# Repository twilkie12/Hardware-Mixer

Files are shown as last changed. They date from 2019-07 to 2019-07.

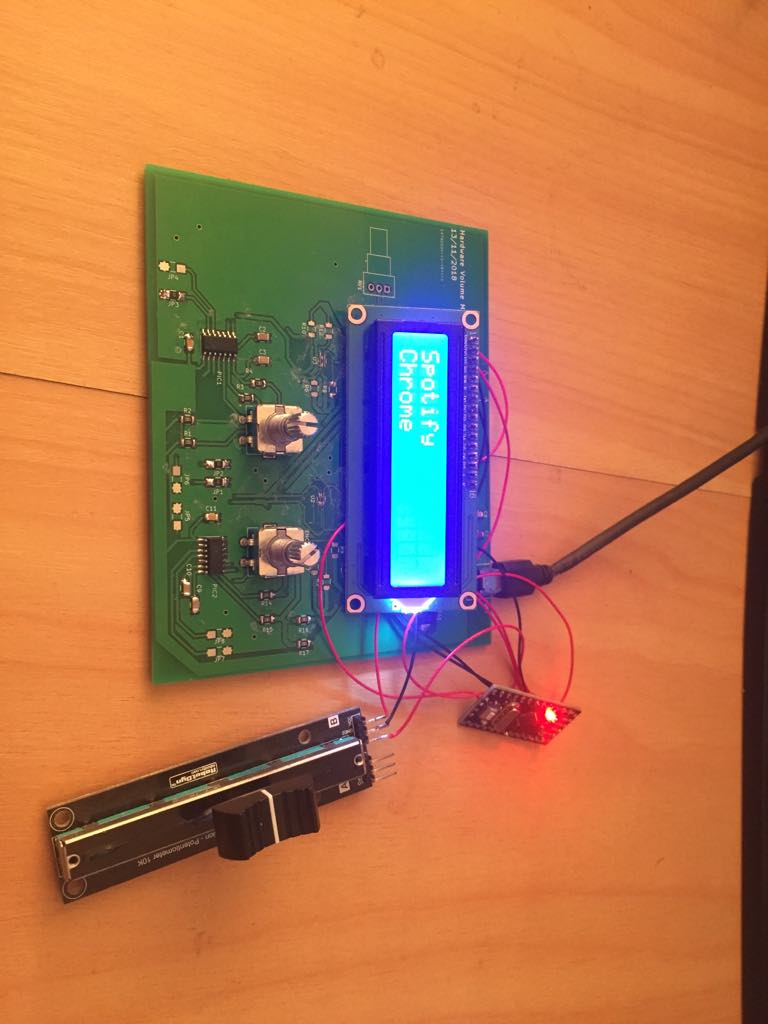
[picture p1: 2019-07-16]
60801276_693158854454214_3320983367419166720_n.jpg

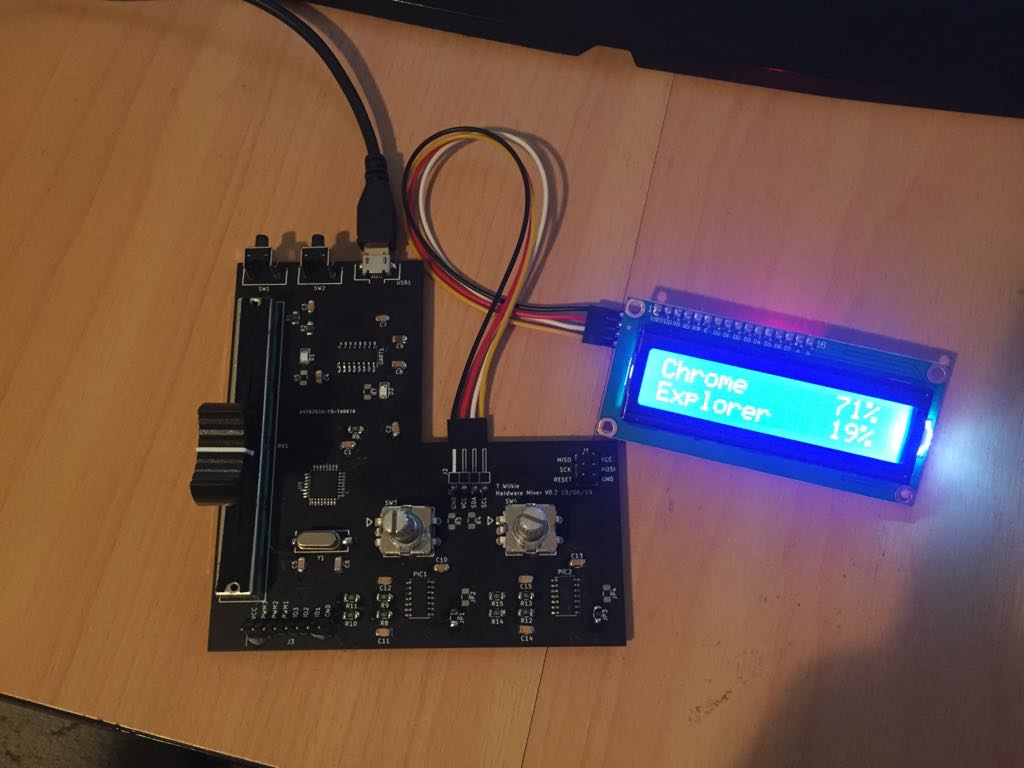
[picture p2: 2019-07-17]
66774168_422680101670621_2241283221188771840_n.jpg

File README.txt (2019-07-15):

As a disclaimer, I am an amateur at programming and hardware design and so cannot guarantee any of this will work for you.
Will only work for Windows 10 but the hardware could easily be used with an equivalent program on Linux.
It's a bit buggy and probably not written to any decent standard but it is what it is.
This document is less of a README and more of a loose, constantly changing list of things I need to do, need to fix, want to add, need 
to look into or just think some time in the future could be interesting to look at. As such it is basically a brain dump and not
hugely important; nothing past the second paragraph will be useful for actually creating/setting up the board.
Will be adding a plastic enclosure at some point, probably 3D printed base with acrylic top.
Ask and I can send you a (possibly assembled for a fee) PCB for cost + shipping, ostensibly to test and help with prototyping but with 
no obligation to do so however any help adding to or fixing things would be appreciated.
I am open to any and all feedback.

If you decide to get the PCB manufactured yourself and put it all together yourself then some notes:

	- The Kicad board routing is currently broken because of the way I did the pours. Rebuilding it will give you a single 5V pour
	  on the top and a single GND pour on the bottom (maybe, your milage may vary). This is an issue because there is supposed to be 
	  THREE small GND zones on the top surface, one each on the right of the PIC16f15323's and one off the GND pin of the micro-usb
	  connector with a single 5V zone on the rest of the surface. I will at some stage fix this but I have already ordered the
	  boards and the file broke afterwards so it is not a top priority for me.
	- The python script looks for a specific serial number on a USB device and then trys to connect to that. You will need to use
	  a CH340B as this is allows you to change the EEPROM and write the serial number to the chip. The software and drivers to
	  do this and use CH340 chips are ahead but I will say that while the drivers are from the manufactuers site the CFG program is
	  not, with the most official looking download being from the WCH forum; and I really cannot condone downloading a random .rar
	  from unknown sources. I have not downloaded the CFG from this source instead I initially found it only on a random chinese
	  filehosting site which is probably even worse.
	  (Drivers: http://www.wch.cn/download/CH341SER_EXE.html, and the program used to configure the EEPROM:
	  http://wch.cn/index.php/bbs/thread-64449-2.html -- Called CH340CFG, there are multiple sources available through google). 
	- As a warning you ONLY want to change the serial number on the chipe, changing VID, or PID WILL make the drivers stop working
	  until you manually reassign the driver to the device, not recommended if you do not know your way around your PC.
	- You will need an Arduino, USBasp or similar to burn the Arduino bootloader to the ATMEGA 168 with Arduino IDE as well as 
	  needing a PICKIT and ZIF socket to flash the PIC's. If you are so inclined adding ISP points to the PCB to flash the PIC's
	  would be very simple and I will likely add them in the next revision.

Idea is for a board with 2 rotary encoders (tried pots, didn't really work nicely), a slide pot and 16x2 LCD screen with PCF85741 i2c
backpack used to control the windows 10 volume mixer program with hardware.

Controls 2 programs volume at a time, with the name of the active programs given on the LCD screen and the active programs changed by
pressing the rotary encoder button. Master volume is controlled by slider.

Uses Atmega 168 (could use 328 easily) with arduino to run the board with PIC16f15323's reading the rotary encoders (Fattoresaimon's
i2cencoder project, https://github.com/Fattoresaimon/i2cencoder). 

AndreMiras's pycaw library used to control Windows volume mixer (https://github.com/AndreMiras/pycaw). 

Francisco Malpartida's i2cliquidcrystal library for arduino (https://bitbucket.org/fmalpartida/new-liquidcrystal/wiki/Home) 
(Need to make sure you have the right one as there are quite a few libraries with the same names with slightly different
implementations)

Uses CH340B USB-Serial chip for it's EEPROM to allow python script to recognise board (http://www.wch.cn/products/CH340.html),
(https://lcsc.com/product-detail/USB_CH340B_C81010.html).

To do:

Biggest thing is to make LCD mount on the pcb directly rather then through floating
Remove i2c backpack and just communicate directly using pins on LCD will reduce cost and hassle
This should reduce footprint and required height of the case as well as look neater with no cables inside casing
Also could make backlight/contrast easily adjustable via mounted pots on PCB - Backlight via PWM + mosfet?

Add mounting holes to PCB
Adjust footprint of 6 pin ISP header to show pin 1
Change names on breakout header to say the pin number it is connected to
Put in solder jumpers to turn enable/disable power and data transmission indicator LED's
Label reset and calibration buttons 

Source dupont right angle 1x4 and 2x3 headers precut - possibly have 2x3 but in bulk only --Done-ish
Config file and possibly send config information to board as part of initilisation
Calibration of slide pot, button done, need to write code
Look at possibly changing usb connector to something stronger then micro b
Finalise case material and design - Clear acrylic laser cut top plate need to decide on bottom half

Python code does everything decently well, need to look at getting a lib for windows media buttons

Errors to solve/fix:

-- This seems to be fixed by using a new windows install
Exception ignored in: <bound method _compointer_base.__del__ of <POINTER(IUnknown) ptr=0x2d31688 at 3000710>>
Traceback (most recent call last):
  File "D:\Programming\Python\lib\site-packages\comtypes\__init__.py", line 918, in __del__
    self.Release()
  File "D:\Programming\Python\lib\site-packages\comtypes\__init__.py", line 1172, in Release
    return self.__com_Release()
OSError: exception: access violation writing 0x00000000
Exception ignored in: <bound method _compointer_base.__del__ of <POINTER(IUnknown) ptr=0x2d31ab0 at 3000cb0>>
Traceback (most recent call last):
  File "D:\Programming\Python\lib\site-packages\comtypes\__init__.py", line 918, in __del__
    self.Release()
  File "D:\Programming\Python\lib\site-packages\comtypes\__init__.py", line 1172, in Release
    return self.__com_Release()
OSError: exception: access violation writing 0x00000000

Seems to be some sort of issue with the ctypes attempting to write to protected memory addresses.
New pointer is being defined and put into memory every time it checks for change in sessions or change in endpoint

The serial com object sometimes has errors, need to find the error message but something about Vtable lookup, rare and also seemingly
fixed on fresh windows install

Prints: (-2004287484, None, (None, None, None, 0, None))
Need to figure out where from and why, prints it because python program prints out errors or serial coms if it gets confused

Occasionally PC doesn't decode serial input, not a big deal it tends to just ignore it and then polls again .2s later

The atmega sometimes gets stuck in a send and will stop working and just be recieving constant request markers from the PC which 
will then write to the screen -- fixed with a timeout kind of thing on both ends

Pressing reset on board takes a significant amount of time for the computer to realise and re-initilize -- Fixed?

Could possibly add PID recognition for programs, default to whatever name is already there but for some programs maybe have a list of
PIDS with names the user wants to have used, ie windows systems sounds can be void, "windowsshellexperience" or "Explorer" depending on
how windows feels on that day a list of known pids with their custom names could be made and edited by the user
Probably should check if program PID's are static or dynamic 
Process is psutil object
	--PID is dynamic but can look up the Process.exe() to see the program file for the sound stream, that should be stable

Could add play/pause, next, back buttons - Need to find python library to send windows keyboard commands and decide on how to send
those/what markers

Make a config file to have some settings in it for the program. Leave a default setting but maybe some adjustable parameters
	-- This could definitly be put into a GUI to control rgb values, backlight brightness, program name recognition etc.

RBG lighting settings could be funny, need to figure out how to send to board 
	How many lights, what type, might need to get drivers, i2c maybe too expensive, worth effort?, probably use config file
		-- Lots of spare PWM pins off IC
		-- Chuck small transistors onto the PWM pins, super cheap to get transistors in packs of 100 or whatever
		-- LED's aren't super cheap but maybe in bulk and would look pretty cool
		-- Dimming for LEDs could be an issue as well as choosing where to put them so they aren't facing up and just blinding
		   the user through the top clear plate, but also bottom of pcb currently planned to be enclosed by casing
  
 Look at getting rid of i2c backpack on LCD to cut cost, have the spare pins for it off IC and it might speed everything up although 
 that hasn't been a noticable problem yet even with only 16MHz atmega168
 		-- Using higher freq is possible with 5V I think, need to have another look at the data sheet
 
 Is current hardware debouncing good enough -- need to get into ece labs for oscills
 
 Fix PCB/schematic design errors -  it's just ugly

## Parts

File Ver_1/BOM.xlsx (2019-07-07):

Part | Footprint | Quantity | Cost each | Total cost | Source | Ordered?
ATMEGA 168 | TQFP-32 7x7mm P0.8mm | 1 | 1 | 1 | Aliexpress | x
PIC 16F15323 | SOIC-14 3.9x8.7mm P1.27mm | 2 |  | 0 | Digikey | x
CH340B | SOP-16 150 MIL | 1 |  | 0 | LCSC | x
0.1uF | 1206 | 8 |  | 0 | Aliexpress | x
20pF | 1206 | 2 |  | 0 | Aliexpress | x
10uF | 1206 | 1 |  | 0 | Aliexpress | x
10nF | 1206 | 4 |  | 0 | Aliexpress | x
Red LED | 1206 | 1 |  | 0 | Aliexpress | x
Blue LED | 1206 | 1 |  | 0 | Aliexpress | x
ADR 0 OHM | 1206 | 2 |  | 0 | Aliexpress | x
R 330 | 1206 | 2 |  | 0 | Aliexpress
1k | 1206 | 1 |  | 0 | Aliexpress
10k | 1206 | 10 |  | 0 | Aliexpress
47k | 1206 | 2 |  | 0 | Aliexpress
10k Slide | Custom | 1 |  | 0 | Aliexpress | x
ISP header | 2x4 P2.54mm | 1 |  | 0 | Aliexpress | x
LCD header | 1x4 P2.54mm | 1 |  | 0 | Aliexpress | x
Breakout header | 1x8 P2.54mm | 1 |  | 0 | Aliexpress | x
Right angle button | Custom | 2 |  | 0 | Aliexpress | x
Encoder | Alps EC11E Switch | 2 |  | 0 | Aliexpress | x
USB microB | Custom, type j6 (?) | 1 |  | 0 | Aliexpress | x
16MHz crystal | HC49S SMD | 1 |  | 0 | Aliexpress | x

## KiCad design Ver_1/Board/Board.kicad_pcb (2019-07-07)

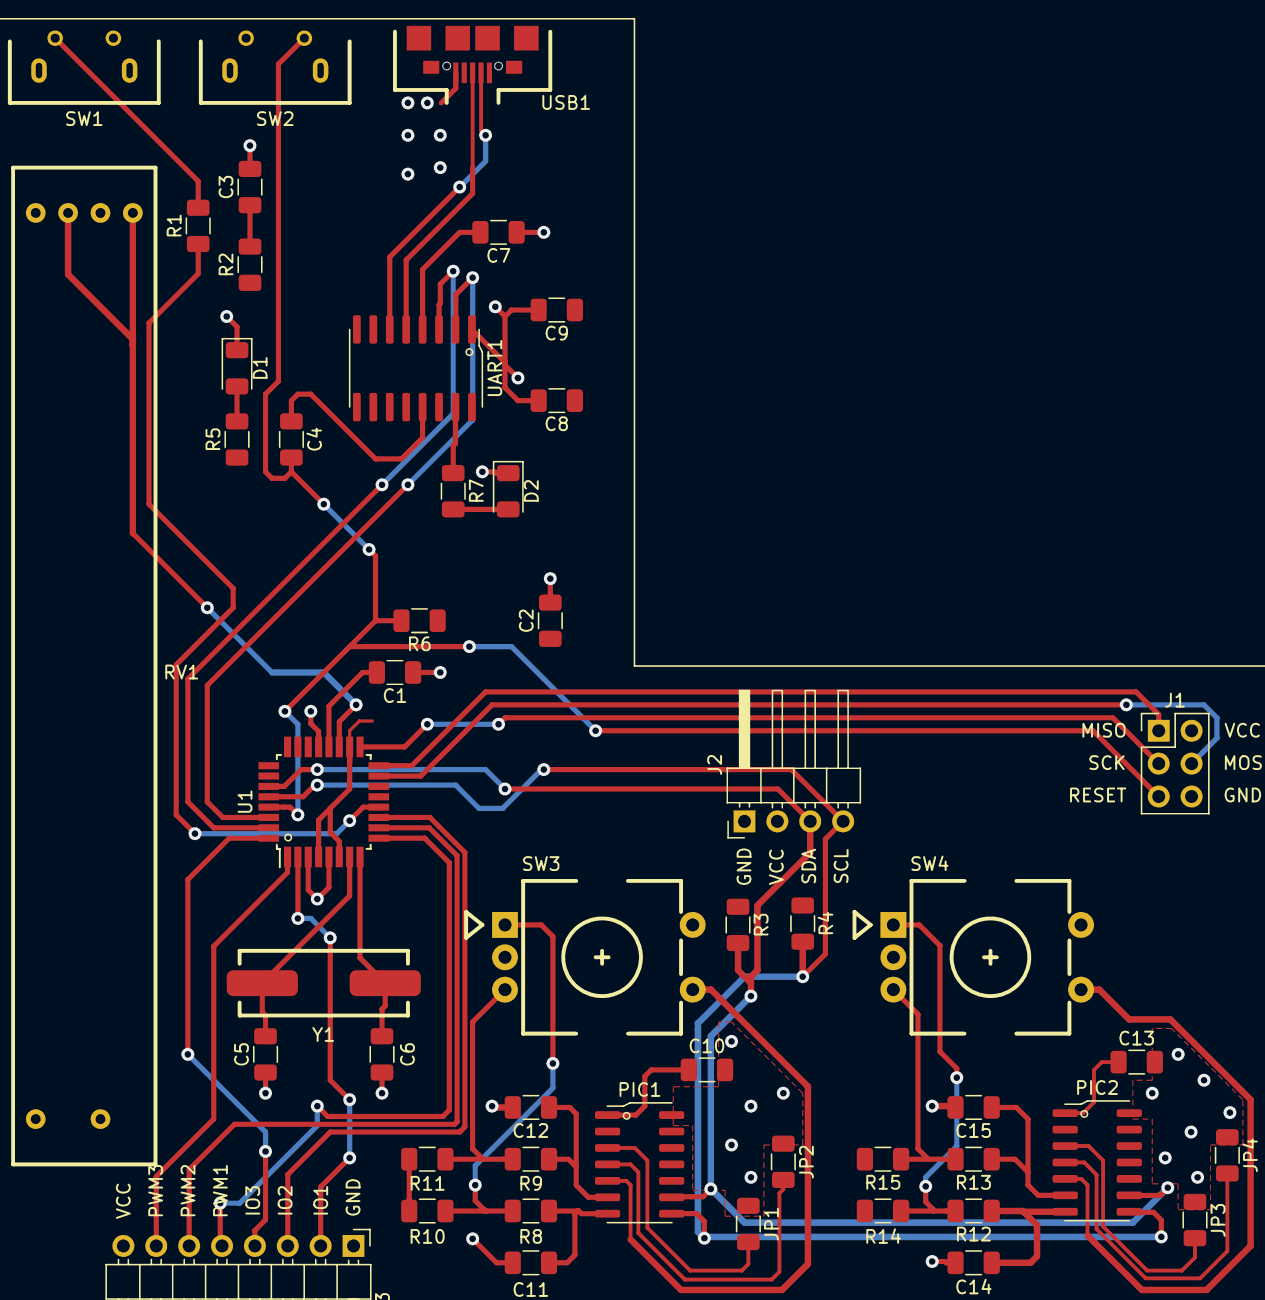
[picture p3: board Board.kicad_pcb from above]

Board: 2 copper layers, 50 parts (0 on the bottom side), 44 nets.

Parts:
C1, C2, C3, C4, C7, C8, C10, C13: 0.1uF; C_1206_3216Metric
C5, C6: 20pF; C_1206_3216Metric
C9: 10uF; C_1206_3216Metric
C11, C12, C14, C15: 10nF; C_1206_3216Metric
D1: RED; LED_1206_3216Metric
D2: BLUE; LED_1206_3216Metric
J1: ISP Header; PinHeader_2x03_P2.54mm_Vertical
J2: LCD Header; PinHeader_1x04_P2.54mm_Horizontal
J3: Breakout; PinHeader_1x08_P2.54mm_Horizontal
JP1, JP3: ADR2; R_1206_3216Metric
JP2, JP4: ADR3; R_1206_3216Metric
PIC1, PIC2: PIC16F15323_I_SL; SOIC-14_3.9x8.7mm_P1.27mm
R1: 1k; R_1206_3216Metric
R2, R6, R8, R9, R10, R11, R12, R13, R14, R15: 10k; R_1206_3216Metric
R3, R4: 47k; R_1206_3216Metric
R5, R7: 330; R_1206_3216Metric
RV1: 10k SLIDE; Slide_potentiometer_Behringer
SW1: Calibration; Right_angle_momentary_button
SW2: Reset; Right_angle_momentary_button
SW3, SW4: Encoder; RotaryEncoder_Alps_EC11E-Switch_Vertical_H20mm
U1: ATmega168PA-AU; TQFP-32_7x7mm_P0.8mm
UART1: CH340B; SOP-16_150MIL
USB1: USB_Micro_B; Micro_B_SMD_G19
Y1: 16MHz; HC49S_SMD_Crystal

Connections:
+5V: C2.1, C8.1, C9.1, C10.1, C13.1, J1.2, J2.2, J3.8, PIC1.1, PIC2.1, R2.1, R3.1, R4.1, R5.1, R6.1, R10.1, R11.2, R14.1, R15.2, RV1.1, U1.4, U1.6, U1.18, UART1.16, USB1.1
/ADC1: RV1.2, U1.19
/CAL: R1.1, U1.12
/I2C Encoder 1/PB: PIC1.5, SW3.2
/I2C Encoder 1/RA: C11.2, PIC1.7, R8.1
/I2C Encoder 1/RB: C12.1, PIC1.6, R9.1
/I2C Encoder 2/PB: PIC2.5, SW4.2
/I2C Encoder 2/RA: C14.2, PIC2.7, R12.1
/I2C Encoder 2/RB: C15.1, PIC2.6, R13.1
/IO1: J3.2, U1.2
/IO2: J3.3, U1.11
/IO3: J3.4, U1.32
/MISO: J1.1, U1.16
/MOSI: J1.4, U1.15
/PWM1: J3.5, U1.9
/PWM2: J3.6, U1.10
/PWM3: J3.7, U1.1
/RESET: C4.2, J1.5, R6.2, SW2.1, U1.29
/SCK: J1.3, U1.17
DATA+: UART1.5, USB1.3
DATA-: UART1.6, USB1.2
DTR: C4.1, UART1.13
GND: C1.1, C2.2, C3.2, C5.1, C6.1, C7.1, C8.2, C9.2, C10.2, C11.1, C12.2, C13.2, C14.1, C15.2, D1.1, D2.1, J1.6, J2.1, J3.1, JP1.1, JP2.1, JP3.1, JP4.1, PIC1.14, PIC2.14, RV1.3, SW1.1, SW2.2, SW3.1, SW3.C, SW4.1, SW4.C, U1.3, U1.5, U1.21, UART1.1, USB1.5
unnamed: C1.2, U1.20
unnamed: C3.1, R2.2
unnamed: C5.2, U1.7, Y1.1
unnamed: C6.2, U1.8, Y1.2
unnamed: C7.2, UART1.4
unnamed: D1.2, R5.2
unnamed: D2.2, R7.2
unnamed: JP1.2, PIC1.3
unnamed: JP2.2, PIC1.4
unnamed: JP3.2, PIC2.3
unnamed: JP4.2, PIC2.4
unnamed: R1.2, SW1.2
unnamed: R7.1, UART1.15
unnamed: R8.2, R10.2, SW3.A
unnamed: R9.2, R11.1, SW3.B
unnamed: R12.2, R14.2, SW4.A
unnamed: R13.2, R15.1, SW4.B
RX: U1.31, UART1.3
SCL: J2.4, PIC1.8, PIC2.8, R4.2, U1.28
SDA: J2.3, PIC1.9, PIC2.9, R3.2, U1.27
TX: U1.30, UART1.2

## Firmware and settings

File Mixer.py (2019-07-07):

import time
import serial
import serial.tools.list_ports
#import logging
from comtypes import CLSCTX_ALL
from ctypes import cast, POINTER
from pycaw.pycaw import ISimpleAudioVolume, AudioUtilities, IAudioEndpointVolume


'''
To do:
Figure out protected memory error
Serial comtype breaks occasionally
How does logging library even work 
e.args -- lachlan?
'''

# Error logging
#logging.basicConfig(filename='Error_log.log', level=logging.DEBUG)



# All Setup

SERIALNUMBER = 494283 # This needs to be assigned to the CH340B so it knows what to connect to
BAUD = 115200 # Needs to be the same as the board BAUDRATE
HANDSHAKE = '@' # Probably not necessary to have a handshake procedure

# It simplifies things greatly by having all these as globals
OPEN_SESSIONS = list() # Audio session objects
SESSION_NAMES = list() # Cleaned names ready to be sent to the board
SESSION_PIDS_GLOBAL = list()

AUDIO_ENDPOINT = None # Will eventually be used as a pointer to the audio endpoint
SESSIONS_CHANGED_FLAG = True

IDENTS = ['z', 'z']
CHANGE_MARKERS = ['#', '$']
VOLUME_BREAK = '!'
VOLUME_REQUEST = '^'
EMPTY_NAME = '-----' # What will be printed on screen if there is no session to go there

VOLUMES = [0, 0, 0]

LASTVOLUME = [0, 0, 0] # Used as a check to reduce the amount of volume changes

# This also slows down the script, lower polling rate will reduce cpu load
# Seconds between volume requests to the board, denominator is Hz polling rate
VOLUME_POLL_TIME = 1 / 5 


VOLUME_CHECKED_TIME = time.time()
AUDIO_ENDPOINT_REFRESH = 5 # Seconds between each check to see if PC audio endpoint has changed
ENDPOINT_CHECKED_TIME = time.time()
SESSION_REFRESH = 2 # Seconds between check to see if the the open audio sessions has changed
SESSION_CHECKED_TIME = time.time()

LAST_LOOP_TIME = 0
WAIT_FLAG = False


'''
Looks for and connects to the mixer via serial number programmed into CH340 chip
Takes no arguments but uses globals of baudrate, serial number, and handshake character
Sends the serial object to the global SERIAL_COM
DONE
'''
def ConnectMixer():

	global SERIAL_COM

	confir = 'f' # Used to recieve handshake from board
	connected = False
	between_tries = 2 # Seconds between connection attempts


	while (connected == False): # Keeps going until the board is connected

		open_ports = serial.tools.list_ports.comports() # Gets a new list of com ports each time

		for port in open_ports:
			device_serial = port.serial_number

			try:
				device_serial = int(device_serial)
				if (SERIALNUMBER == device_serial): # If it is the mixer board
					com_channel = port.device # Grabs the com port address, ie 'COM3'

			except:
				None
               
 


		try: 
			SERIAL_COM = serial.Serial(com_channel, BAUD, timeout=0) # Connects to port
			connected = True

		except:
			time.sleep(between_tries)



	while (confir != HANDSHAKE):

		SERIAL_COM.write(HANDSHAKE.encode())
		time.sleep(0.1)
		confir = SERIAL_COM.read().decode()
		SERIAL_COM.reset_output_buffer() # Clears the handshake and rewrites it if there is no response


	SERIAL_COM.reset_output_buffer()
	SERIAL_COM.reset_input_buffer()


	return
	
	
'''
Gets session objects list and a cleaned name list
Removes any sessions without a name or process
Takes no arguments
Will set SESSIONS_CHANGED_FLAG if there is a change in the open audio sessions
Returns none, but writes the lists to the global variables of OPEN_SESSIONS and SESSION_NAMES
DONE
'''
def AudioSessions():
	
	global OPEN_SESSIONS, SESSION_NAMES, SESSIONS_CHANGED_FLAG, SESSION_CHECKED_TIME, SESSION_PIDS_GLOBAL
	
	current_sessions = AudioUtilities.GetAllSessions() # Gets a list of all current audio session objects
	cleaned_sessions = []
	session_pids = []

	for session in current_sessions:		
		
		if (session.Process != None):
			cleaned_sessions.append(session)
			session_pids.append(session.Process.pid)
			
		else:
			
			None

		
	if session_pids != SESSION_PIDS_GLOBAL: # Will only change things if it is different to what is already there
	
		SESSIONS_CHANGED_FLAG = True
		
		SESSION_PIDS_GLOBAL = session_pids
		
		OPEN_SESSIONS.clear()
		SESSION_NAMES.clear()
		
		for session in cleaned_sessions: # Steps through the audio sessions
		
			name = session.Process.name() # Reads name of session
			name = name[0:-4] # Takes the .exe off the name
			name = name[: 16] # Ensures the name is not too long for the screen
			OPEN_SESSIONS.append(session.SimpleAudioVolume) # List of the session objects, these are what are used to change the volume
			SESSION_NAMES.append(name.capitalize()) # List of the session names, capitalized
			
	
	SESSION_CHECKED_TIME = time.time()
	
	return None

	
'''
Goes through and sees if any volume values need to be changed and then changes them
Will not change the volume if the new value is within 1% of the old one
Each encoder step is 2% if RMOD_X2 is set (or 1% with RMOD_X1)
Uses both global volume lists and the global idents list as well as the global AUDIO_ENDPOINT
Returns none
DONE
'''
def SetVolumes():

	global LASTVOLUME
	
	for channel in range(0, 3):
	
		if (abs(LASTVOLUME[channel] - VOLUMES[channel]) > 1): # Try and reduce the amount of times the volume is changed
	
			LASTVOLUME[channel] = VOLUMES[channel]
		
			if (channel == 2): # Master volume
	
				AUDIO_ENDPOINT.SetMasterVolumeLevelScalar(VOLUMES[2] / 100, None)
		
			else:
	
				id = IDENTS[channel]
				
				if (id != 'z'):
					OPEN_SESSIONS[id].SetMasterVolume(VOLUMES[channel] / 100, None) # Volume value is 0 - 1
	
	return None


'''	
Changes the active programs being managed
The channel for which the program is being changed
Uses the global lists of session names and objects
Changes the values in the global IDENTS list 
'z' is used as an identifier for when there is less then 2 open sessions and the identifier is empty
Returns none
DONE
'''
def ChangeIdents(channel):
	
	global IDENTS
	
	SERIAL_COM.write(CHANGE_MARKERS[channel].encode())
	
	if (len(SESSION_NAMES) == 0):
		IDENTS = ['z', 'z']
		
	elif (len(SESSION_NAMES) == 1): 
		IDENTS = [0, 'z']
	
	else:
		
		if (IDENTS[channel] == 'z'):
			IDENTS[channel] = 0 # If the ident was previously empty then gives it a channel to allow next part to work
		
		id = (IDENTS[channel] + 1) % len(SESSION_NAMES) # Increments IDENT by 1
		
		if (id == IDENTS[channel - 1]): # Checks if IDENT is already being used and if it is changes it
		
			id = (IDENTS[channel] + 2) % len(SESSION_NAMES)	
			
		
		IDENTS[channel] = id
	
		
	return None
	
	
'''
Sends the name of the program and its volume to the board to be displayed
Takes the channel being changed and a boolean of whether the change marker is expected by the board
If the board requested the channel change then the marker prefix is unnecessary but if the PC has decided to change 
then the prefix is used to tell the board to expect a name + volume which is read from the session and put into VOLUMES
Returns none
DONE
'''
def SendSessionName(channel):

	global VOLUMES
		
	id = IDENTS[channel]
	
	if (id == 'z'):
		
		SERIAL_COM.write(EMPTY_NAME.encode())
		SERIAL_COM.write(CHANGE_MARKERS[channel].encode())
		SERIAL_COM.write(str(VOLUMES[channel]).encode())
		
		
	else:
		
		SERIAL_COM.write(SESSION_NAMES[id].encode())
		
		SERIAL_COM.write(CHANGE_MARKERS[channel].encode())
		master_vol = str((OPEN_SESSIONS[id].GetMasterVolume()) * 100)
		VOLUMES[channel] = master_vol.split('.')[0]
		SERIAL_COM.write(VOLUMES[channel].encode())
		
		
	SERIAL_COM.write(VOLUME_BREAK.encode())
	
	return None
	
	
'''
If a new audio device is plugged in then there will be a change in the audio endpoint and this will need to be monitored for
This function sees if the endpoint is the same as before
If the endpoint has changed it sets it to whatever the PC is currently outputting to
Also forces a volume change of the master volume if the endpoint changes because windows does not carry over the volume
Returns none
DONE
'''
def CheckAndSetAudioEndpoint():
	
	global AUDIO_ENDPOINT, ENDPOINT_CHECKED_TIME
	
	device = AudioUtilities.GetSpeakers()
	interface = device.Activate(IAudioEndpointVolume._iid_, CLSCTX_ALL, None)
	new_endpoint = cast(interface, POINTER(IAudioEndpointVolume))
	
	if (new_endpoint != AUDIO_ENDPOINT):
		
		AUDIO_ENDPOINT = new_endpoint
		AUDIO_ENDPOINT.SetMasterVolumeLevelScalar(VOLUMES[2] / 100, None)
	
	ENDPOINT_CHECKED_TIME = time.time()
	return None

	
'''
Requests a list of volumes from the board using VOLUME_REQUEST
Expects a list of 3 volumes between 0 and 100 prefixed, suffixed and broken by VOLUME_BREAK
Writes these volumes into VOLUMES
Returns True if volumes were recieved and false if some other command was recieved
NEED TO GET TIMINGS
DONE OTHERWISE
'''
def RequestVolumes():

	global VOLUMES, VOLUME_CHECKED_TIME
	
	while (SERIAL_COM.in_waiting != 0):
	
		data = SERIAL_COM.read()
		if (data == HANDSHAKE):
			Initilize()
					
		elif (data == CHANGE_MARKERS[0]):
				
			ChangeIdents(0)
			SendSessionName(0)
					
		elif (data == CHANGE_MARKERS[1]):
						
			ChangeIdents(1)
			SendSessionName(1)
					
		else:
							
			data = SERIAL_COM.readline()
			print(data)
			
			
			
	VOLUME_CHECKED_TIME = time.time()
	
	SERIAL_COM.write(VOLUME_REQUEST.encode())
	request_sent = time.time()
	
	while (SERIAL_COM.in_waiting == 0 and (time.time() - request_sent < 0.5)):
		None # Waiting for a response
	
	if (SERIAL_COM.in_waiting == 0):
		
		# No response after a little bit, assume something is broken
		SERIAL_COM.write(HANDSHAKE.encode())# Try writing a handshake and seeing if there is a response
		
		while (SERIAL_COM.in_waiting == 0 and (time.time() - request_sent < 0.2)):
			None # Waiting for a response again
			
			
		if (SERIAL_COM.in_waiting != 0):
			data = SERIAL_COM.read().decode()

			
			if (data == HANDSHAKE):
				
				Initilize()
				return
				
		
		else:
		
			Initilize()
			return()
			
	
	volume_string = SERIAL_COM.readline().decode()

	
	if (CHANGE_MARKERS[0] in volume_string):
		
		ChangeIdents(0)

	
	elif (CHANGE_MARKERS[1] in volume_string):
		
		ChangeIdents(1)
		
	elif (HANDSHAKE in volume_string):
		
		None
	
	else:
		
		try:	
			volume_string = volume_string.strip(VOLUME_BREAK).split(VOLUME_BREAK) 
			VOLUMES = [int(volume) for volume in volume_string]
			return True
			
		except:
			None
		
		
	return False
		
	
'''	
Will only run on first connection or if the board is disconnected and reconnected 
The loop will stay in this function (actually in ConnectMixer) until serial com is working
Gets everything set up
Returns None
MAY NEED TO GET SOME TIMINGS
DONE OTHERWISE
'''
def Initilize():
	
	global SESSION_CHECKED_TIME, ENDPOINT_CHECKED_TIME, VOLUME_CHECKED_TIME
	
	try:
		# Ensures that everything is starting from scratch. Especially useful for when the board reset is pushed
		SERIAL_COM.close()
	
	except:
		None
		
		
	# Connects board and prepares sessions and endpoint
	ConnectMixer()
	AudioSessions()
	SESSION_REFRESH = time.time()
	
	RequestVolumes() # This is basically only to get the master volume to then apply to the endpoint
	VOLUME_CHECKED_TIME = time.time()
	
	CheckAndSetAudioEndpoint()
	ENDPOINT_CHECKED_TIME = time.time()
	
	# Sets sessions being controlled and sends their names and current volumes
	
	ChangeIdents(0)
	SendSessionName(0) 
	ChangeIdents(1)
	SendSessionName(1)
	
	return None
	

'''
Main loop function that will run constantly
Needs to:
	check board is connected
	if disconnected to do initial setup again (This will also reconnect board)
	request volumes
	set volumes
	keep track of endpoints
	keep track of open sessions	
DONE
'''
def Main():
	
	global SESSIONS_CHANGED_FLAG, LAST_LOOP_TIME, WAIT_FLAG
	
	
	try:

		if (((time.time() - LAST_LOOP_TIME) > VOLUME_POLL_TIME) or WAIT_FLAG == False):
		# Trying to reduce the cpu load by sleeping between the volume requests
			
			WAIT_FLAG = False
			
			
			if (SERIAL_COM.in_waiting != 0):
				
				data = SERIAL_COM.read().decode()
				
				if (data == HANDSHAKE):
					Initilize()
					
				elif (data == CHANGE_MARKERS[0]):
				
					ChangeIdents(0)
					SendSessionName(0)
					
				elif (data == CHANGE_MARKERS[1]):
					
					ChangeIdents(1)
					SendSessionName(1)
				
				else:
						
					data = SERIAL_COM.readline()
					print(data)
					
			
			elif ((time.time() - ENDPOINT_CHECKED_TIME) >= AUDIO_ENDPOINT_REFRESH):
					
				CheckAndSetAudioEndpoint()

					
			elif ((time.time() - SESSION_CHECKED_TIME) >= SESSION_REFRESH):
				
				AudioSessions()
					
				if (SESSIONS_CHANGED_FLAG == True):
						
					# Sets sessions being controlled and sends their names and current volumes
					ChangeIdents(0)
					SendSessionName(0) 
					ChangeIdents(1)
					SendSessionName(1)
						
					SESSIONS_CHANGED_FLAG = False
				
			else:
				
				flag = RequestVolumes()
				
				WAIT_FLAG = True
				LAST_LOOP_TIME = time.time()
				
				if (flag == True):
					SetVolumes()

		else:
			
			time.sleep(VOLUME_POLL_TIME)
	
	
	except serial.SerialException:
	
		Initilize()
		SESSIONS_CHANGED_FLAG = False
		
	except Exception as e:
	
		print(e.args)

	
	return None
	

Initilize()

while True:
	
	try:
		Main()
		
	except Exception as e:
		
		print(e.args)
		print('------------------------')		
		print(e)
